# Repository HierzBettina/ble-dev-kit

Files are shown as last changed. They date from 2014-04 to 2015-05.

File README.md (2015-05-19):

*Note*: I have ceased working on projects with the HM-10 and the CC2541. The difficulties of dealing with the IAR toolchain are too great. I now recommend [ARM mbed solutions](https://developer.mbed.org/platforms/Nordic-nRF51822/) if you intend to pursue developing a BLE peripheral. I am leaving the resources I was able to gather online in case someone has use for them, but I cannot provide support.

BLE Dev Kit
====

Getting into low power Bluetooth peripheral prototyping can get expensive quickly. This project aims to chart out and the document the cheapest, easiest way to create a true, custom peripheral with its own profile. Head on over the [wiki](https://github.com/nickswalker/ble-dev-kit/wiki) to read more.

Hardware
----
A sub ten dollar CC2541 development board based on the HM-10 module. This board is a fork of Ladvien's excellent work with the module.
 
Firmware
----
On-board application and profile examples.

Software
----
Client application examples (iOS).

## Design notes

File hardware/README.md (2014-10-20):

### Who are These Boards For?

Two groups of people: Those wanting to get breadboard, quasi-UART-over-BLE through the modules’ firmware and those wanting a cheaper, more flexible alternative to TI's CC2541 dev kits.

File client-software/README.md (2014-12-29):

Client Software
====

RSSI Probe
------

An iOS app that displays the RSSI values of three devices. Load a profile that advertises at a regular interval onto some HM-10s and then code their UUIDs into the source. Experiment with interesting arrangements and configurations. Includes a useful CSV logging capability so you can work with the data. Just plug your device into iTunes when your done and copy the log from the applications pane. Note that the app will not compile in the simulator; CoreBluetooth requires an actual device.

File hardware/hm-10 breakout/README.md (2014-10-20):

HM-10 Breakout Board
====================

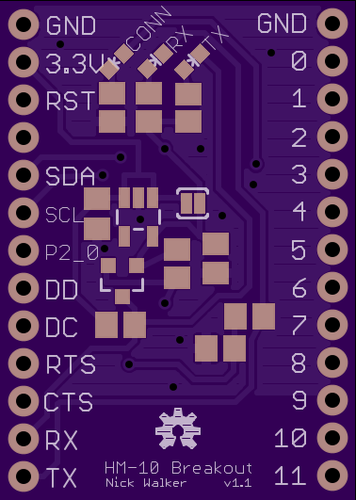
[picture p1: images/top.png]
Top

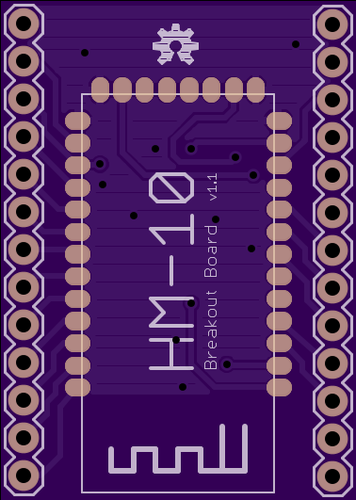
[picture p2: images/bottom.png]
Bottom


This is a slight modification of [Ladvien's board](https://github.com/Ladvien/HM-10). This version has more accurate pin notations and removes routes to unused pins on the HM-10, thereby shrinking the overall footprint of the board. 
The HM-10's on board TI CC2541 is fully programmable with CC-Debugger or SmartRF04EB. See this repo's [wiki](https://github.com/nickswalker/HM-10-breakout-board/wiki) for more resources.

## Bill of Materials

If you are planning on ordering the PCB through OSHPark, keep in mind that you will receive three copies. You may want to go ahead and order three times as many components. Digi-Key numbers are provided as a courtesy; check eBay or any other preferred supplier for better pricing. As long as the component matches the packaging a specifications, it should be fine.

At a bare minimum, the PCB and the HM-10 module are required. If you want to use UART but only have the capability of providing 5v, you will want to populate the level conversion components. However, this is /grossly/ inefficient and defeats the purpose of using a low power connection technology. Bridge the solder jumper to bypass the regulator circuit. You may consider simply regulating off board for development, using a cheap level converter like [this one](http://www.ebay.com/itm/1PC-New-5V-3V-IIC-UART-Level-Converter-Module-Adapter-4-Way-For-Arduino-/251384699933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).

Part (Digi-Key #) | Quantity | Optional (Required For)
:---------------- | :-------:| :----------------------
[Breakout PCB](https://oshpark.com/shared_projects/A6hoH6Fi)  | 1 | No
[HM-10 Module](http://www.fasttech.com/products/0/10004051/1292002-ti-cc2540-bluetooth-40-ble-2540-transparent-serial) | 1 | No
[0805 20kΩ Resistor](http://www.digikey.com/product-detail/en/RMCF0805JT20K0/RMCF0805JT20K0CT-ND/1942580) (RMCF0805JT20K0CT-ND) | 1 | Yes (UART level conversion)
[0805 10kΩ Resistor](http://www.digikey.com/product-detail/en/RMCF0805FT10K0/RMCF0805FT10K0DKR-ND/1943341) (RMCF0805FT10K0CT-ND) | 3 | Yes (UART level conversion)
[0603 LED](http://www.digikey.com/product-detail/en/LTST-C191KRKT/160-1447-1-ND/386836) (160-1447-1-ND) | 1 | Yes (LEDs)
[0603 LED (>3v drop)](http://www.digikey.com/product-detail/en/APT1608QBC%2FD/754-1434-1-ND/2163792) (754-1434-1-ND) | 2 | Yes (LEDs)
[0805 470Ω Resistor](http://www.digikey.com/product-detail/en/RMCF0805JG470R/RMCF0805JG470RCT-ND/4425246) (RMCF0805JG470RCT-ND) | 3 | Yes (LEDs)
[SOT-23 MCP1700 Voltage Regulator](http://www.digikey.com/product-detail/en/MCP1700T-3302E%2FTT/MCP1700T3302ETTCT-ND/652677) (MCP1700T3302ETTCT-ND) | 1 | Yes (voltage regulator)
[0805 1uF Capacitor](http://www.digikey.com/product-detail/en/JMK105BJ105KV-F/587-1231-1-ND/931008) (587-1231-1-ND) | 1 | Yes (Voltage regulator)

The silkscreen doesn't include values, so be sure to have it open in front of you while you assemble.

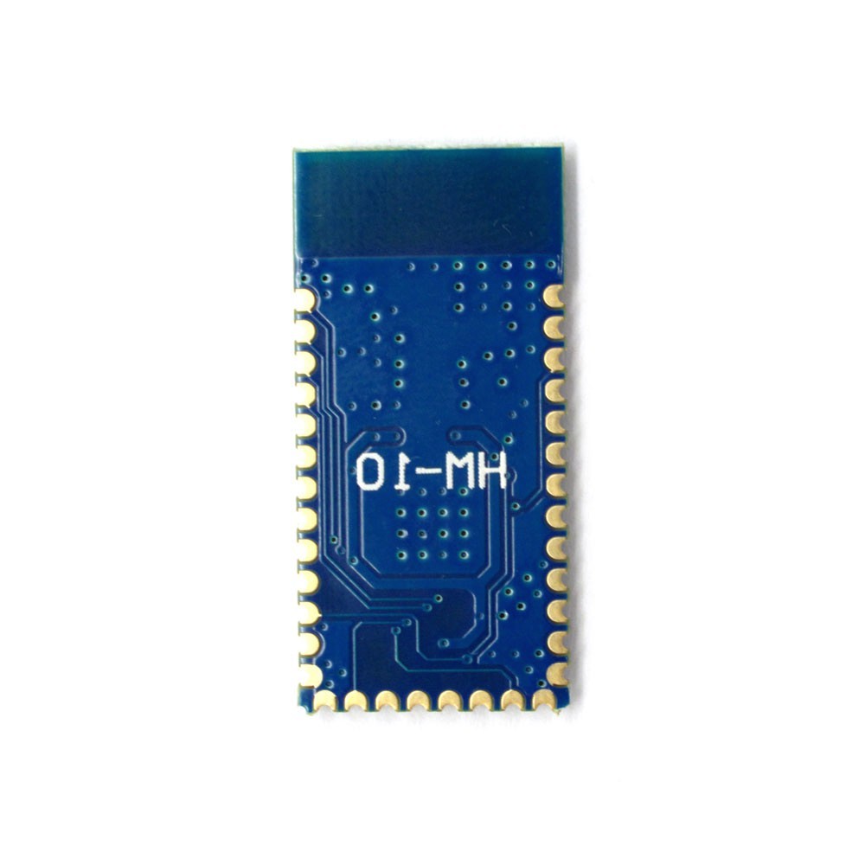
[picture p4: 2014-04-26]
images/hm-10-back.jpg

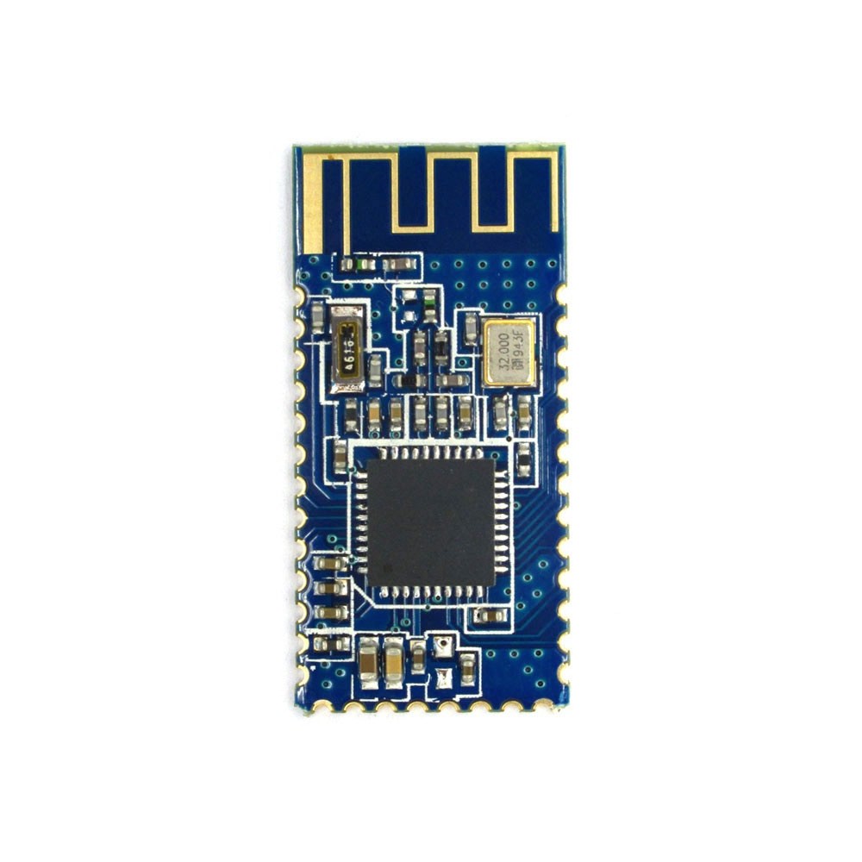
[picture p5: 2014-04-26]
images/hm-10-front.jpg

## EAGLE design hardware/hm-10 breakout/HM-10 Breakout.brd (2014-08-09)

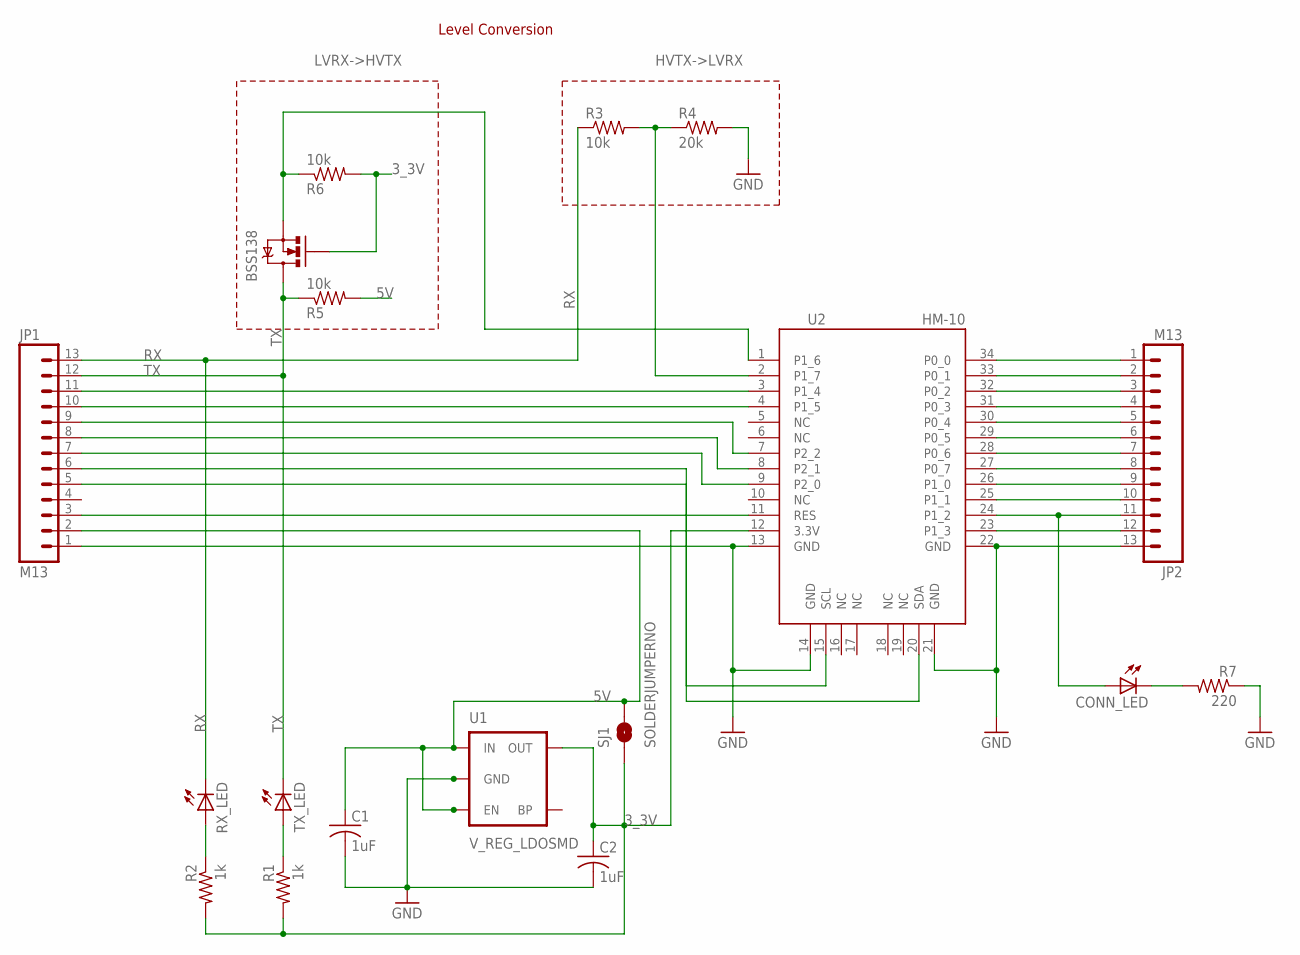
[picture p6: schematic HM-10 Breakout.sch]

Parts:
BSS138: MOSFET-NCHANNELSMD; SOT23-3
C1, C2: 1uF; C0805K
CONN_LED: LED0603; LED-0603
JP1, JP2: M13; 1X13
R1, R2: 1k; M0805
R3, R5, R6: 10k; M0805
R4: 20k; M0805
R7: 220; M0805
RX_LED: LED0603; LED-0603
SJ1: SOLDERJUMPERNO; SJ_2S-NO
TX_LED: LED0603; LED-0603
U1: V_REG_LDOSMD; SOT23-5
U2: HM-10

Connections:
3_3V: BSS138.1 (G), C2.1, R1.2, R2.2, R6.2, SJ1.1, U1.5 (OUT), U2.12 (3.3V)
5V: C1.1, JP1.2, R5.2, SJ1.2, U1.1 (IN), U1.3 (EN)
GND: C1.2, C2.2, JP1.1, JP2.13, R4.2, R7.1, U1.2 (GND), U2.13 (GND), U2.14 (GND), U2.21 (GND), U2.22 (GND)
HVTX->LVRX: R3.2, R4.1, U2.2 (P1_7)
LVRX->HVTX: BSS138.2 (S), R6.1, U2.1 (P1_6)
unnamed: CONN_LED.A, JP2.11, U2.24 (P1_2)
unnamed: JP1.3, U2.11 (RES)
unnamed: JP1.5, U2.15 (SCL)
unnamed: JP1.9, U2.7 (P2_2)
unnamed: JP1.8, U2.8 (P2_1)
unnamed: JP1.7, U2.9 (P2_0)
unnamed: JP2.10, U2.25 (P1_1)
unnamed: JP1.6, U2.20 (SDA)
unnamed: JP1.10, U2.4 (P1_5)
unnamed: JP1.11, U2.3 (P1_4)
unnamed: JP2.9, U2.26 (P1_0)
unnamed: JP2.8, U2.27 (P0_7)
unnamed: JP2.7, U2.28 (P0_6)
unnamed: JP2.6, U2.29 (P0_5)
unnamed: JP2.5, U2.30 (P0_4)
unnamed: JP2.4, U2.31 (P0_3)
unnamed: JP2.3, U2.32 (P0_2)
unnamed: JP2.2, U2.33 (P0_1)
unnamed: JP2.1, U2.34 (P0_0)
unnamed: JP2.12, U2.23 (P1_3)
unnamed: R1.1, TX_LED.A
unnamed: CONN_LED.C, R7.2
unnamed: R2.1, RX_LED.A
RX: JP1.13, R3.1, RX_LED.C
TX: BSS138.3 (D), JP1.12, R5.1, TX_LED.C

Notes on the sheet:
Level Conversion

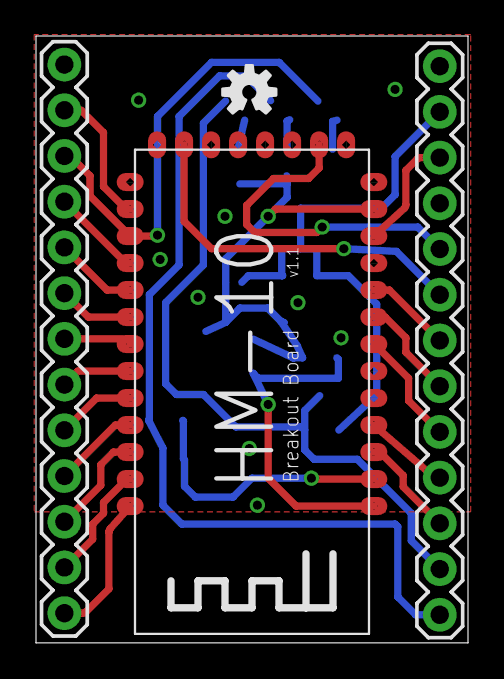
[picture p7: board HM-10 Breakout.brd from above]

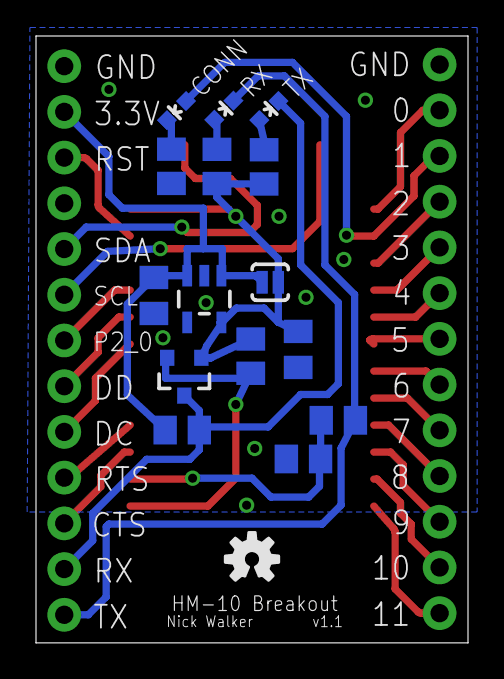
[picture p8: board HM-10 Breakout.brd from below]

Board: 2 copper layers, 24.0 x 33.7 mm, 20 parts (16 on the bottom side), 30 nets.

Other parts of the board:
U$1, U$2: OSHW-LOGO-S

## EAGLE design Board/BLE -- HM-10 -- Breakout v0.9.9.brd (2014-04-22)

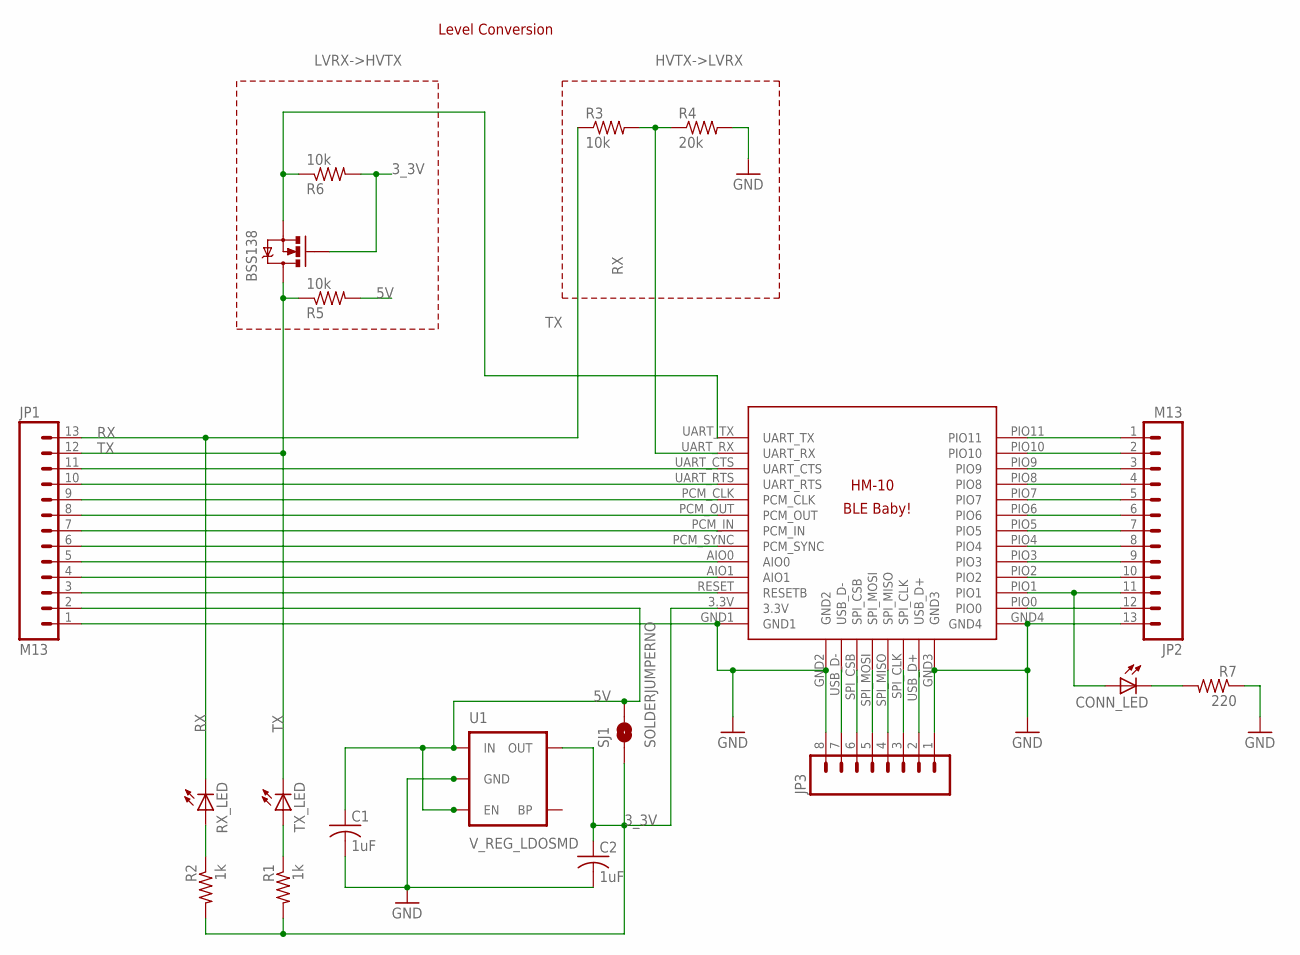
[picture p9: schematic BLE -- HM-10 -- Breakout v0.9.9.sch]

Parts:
BSS138: MOSFET-NCHANNELSMD; SOT23-3
C1, C2: 1uF; C0805K
CONN_LED: LED0603; LED-0603
JP1, JP2: M13; 1X13
JP3: M081X08; 1X08
R1, R2: 1k; M0805
R3, R5, R6: 10k; M0805
R4: 20k; M0805
R7: 220; M0805
RX_LED: LED0603; LED-0603
SJ1: SOLDERJUMPERNO; SJ_2S-NO
TX_LED: LED0603; LED-0603
U1: V_REG_LDOSMD; SOT23-5
U$1: BLE-HM-10

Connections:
3_3V: BSS138.1 (G), C2.1, R1.2, R2.2, R6.2, SJ1.1, U1.5 (OUT), U$1.3.3V
5V: C1.1, JP1.2, R5.2, SJ1.2, U1.1 (IN), U1.3 (EN)
GND: C1.2, C2.2, JP1.1, JP2.13, JP3.1, JP3.8, R4.2, R7.1, U1.2 (GND), U$1.GND1, U$1.GND2, U$1.GND3, U$1.GND4
HVTX->LVRX: R3.2, R4.1, U$1.UART_RX
LVRX->HVTX: BSS138.2 (S), R6.1, U$1.UART_TX
unnamed: CONN_LED.A, JP2.11, U$1.PIO1
unnamed: JP1.3, U$1.RESET (RESETB)
unnamed: JP1.4, U$1.AIO1
unnamed: JP1.5, U$1.AIO0
unnamed: JP1.6, U$1.PCM_SYNC
unnamed: JP1.7, U$1.PCM_IN
unnamed: JP1.8, U$1.PCM_OUT
unnamed: JP1.9, U$1.PCM_CLK
unnamed: JP1.10, U$1.UART_RTS
unnamed: JP1.11, U$1.UART_CTS
unnamed: JP2.1, U$1.PIO11
unnamed: JP2.2, U$1.PIO10
unnamed: JP2.3, U$1.PIO9
unnamed: JP2.4, U$1.PIO8
unnamed: JP2.5, U$1.PIO7
unnamed: JP2.6, U$1.PIO6
unnamed: JP2.7, U$1.PIO5
unnamed: JP2.8, U$1.PIO4
unnamed: JP2.9, U$1.PIO3
unnamed: JP2.10, U$1.PIO2
unnamed: R1.1, TX_LED.A
unnamed: JP2.12, U$1.PIO0
unnamed: CONN_LED.C, R7.2
unnamed: R2.1, RX_LED.A
unnamed: JP3.2, U$1.USB_D+
unnamed: JP3.3, U$1.SPI_CLK
unnamed: JP3.4, U$1.SPI_MISO
unnamed: JP3.5, U$1.SPI_MOSI
unnamed: JP3.6, U$1.SPI_CSB
unnamed: JP3.7, U$1.USB_D-
RX: JP1.13, R3.1, RX_LED.C
TX: BSS138.3 (D), JP1.12, R5.1, TX_LED.C

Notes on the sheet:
Level Conversion

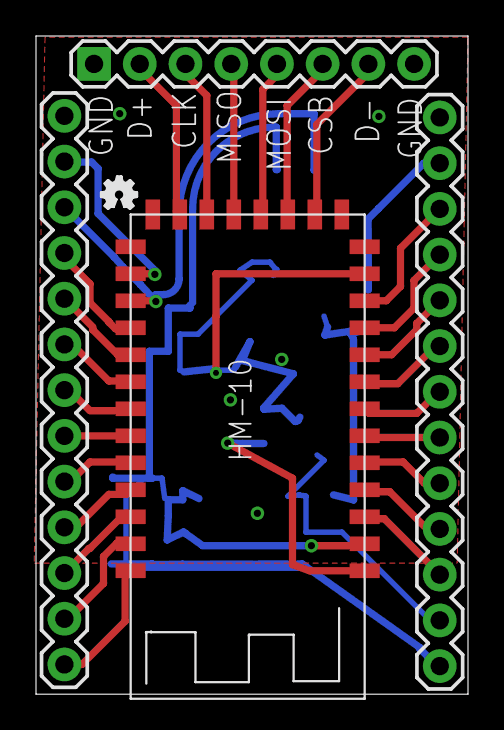
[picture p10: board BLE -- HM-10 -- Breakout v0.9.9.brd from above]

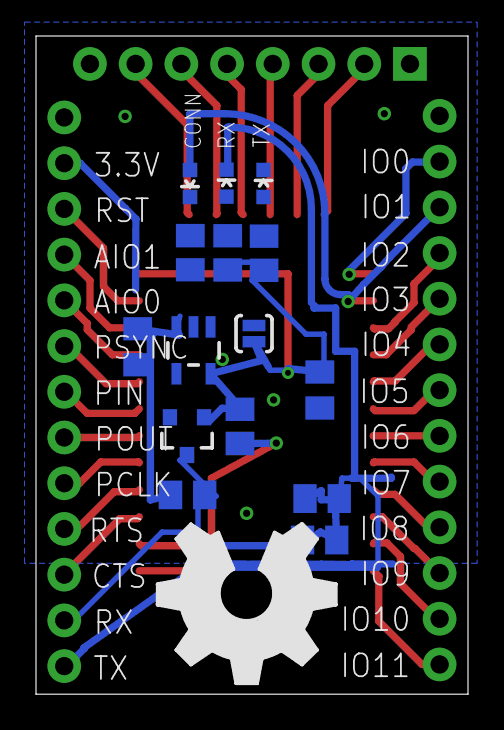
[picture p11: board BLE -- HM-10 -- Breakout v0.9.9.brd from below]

Board: 2 copper layers, 24.0 x 36.6 mm, 21 parts (16 on the bottom side), 37 nets.

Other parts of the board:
U$2: OSHW_FILLX350_NOTEXT
U$3: OSHW_FILLX70_NOTEXT

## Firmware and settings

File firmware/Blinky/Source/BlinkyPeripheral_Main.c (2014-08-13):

/* Hal Drivers */
#include "hal_types.h"
#include "hal_key.h"
#include "hal_timer.h"
#include "hal_drivers.h"
#include "hal_led.h"

/* OSAL */
#include "OSAL.h"
#include "OSAL_Tasks.h"
#include "OSAL_PwrMgr.h"
#include "osal_snv.h"

/**************************************************************************************************
 * FUNCTIONS
 **************************************************************************************************/

/* This callback is triggered when a key is pressed */
void MSA_Main_KeyCallback(uint8 keys, uint8 state);

int main(void)
{
  /* Initialize hardware */
  HAL_BOARD_INIT();

  /* Initialze the HAL driver */
  HalDriverInit();

  /* Initialize NV system */
  osal_snv_init();

  /* Initialize the operating system */
  osal_init_system();

  /* Enable interrupts */
  HAL_ENABLE_INTERRUPTS();

  #if defined ( POWER_SAVING )
    osal_pwrmgr_device( PWRMGR_BATTERY );
  #endif

  /* Start OSAL */
  osal_start_system(); // No Return from here

  return 0;
}

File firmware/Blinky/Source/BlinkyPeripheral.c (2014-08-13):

#include "bcomdef.h"
#include "OSAL.h"
#include "OSAL_PwrMgr.h"

#include "OnBoard.h"
#include "hal_adc.h"
#include "hal_led.h"
#include "hal_key.h"
#include "hal_lcd.h"

#include "gatt.h"

#include "hci.h"

#include "gapgattserver.h"
#include "gattservapp.h"
#include "devinfoservice.h"
#include "blinkyProfile.h"

#include "peripheral.h"

#include "gapbondmgr.h"

#include "BlinkyPeripheral.h"

#if defined FEATURE_OAD
  #include "oad.h"
  #include "oad_target.h"
#endif


/*********************************************************************
 * CONSTANTS
 */

// How often to perform periodic event
#define SBP_PERIODIC_EVT_PERIOD                   500

// What is the advertising interval when device is discoverable (units of 625us, 160=100ms)
#define DEFAULT_ADVERTISING_INTERVAL          160

// Limited discoverable mode advertises for 30.72s, and then stops
// General discoverable mode advertises indefinitely

#define DEFAULT_DISCOVERABLE_MODE             GAP_ADTYPE_FLAGS_GENERAL


// Minimum connection interval (units of 1.25ms, 80=100ms) if automatic parameter update request is enabled
#define DEFAULT_DESIRED_MIN_CONN_INTERVAL     80

// Maximum connection interval (units of 1.25ms, 800=1000ms) if automatic parameter update request is enabled
#define DEFAULT_DESIRED_MAX_CONN_INTERVAL     800

// Slave latency to use if automatic parameter update request is enabled
#define DEFAULT_DESIRED_SLAVE_LATENCY         0

// Supervision timeout value (units of 10ms, 1000=10s) if automatic parameter update request is enabled
#define DEFAULT_DESIRED_CONN_TIMEOUT          1000

// Whether to enable automatic parameter update request when a connection is formed
#define DEFAULT_ENABLE_UPDATE_REQUEST         TRUE

// Connection Pause Peripheral time value (in seconds)
#define DEFAULT_CONN_PAUSE_PERIPHERAL         6

// Company Identifier: Texas Instruments Inc. (13)
#define TI_COMPANY_ID                         0x000D

#define INVALID_CONNHANDLE                    0xFFFF

// Length of bd addr as a string
#define B_ADDR_STR_LEN                        15

/*********************************************************************
 * LOCAL VARIABLES
 */
static uint8 simpleBLEPeripheral_TaskID;   // Task ID for internal task/event processing

static gaprole_States_t gapProfileState = GAPROLE_INIT;

// GAP - SCAN RSP data (max size = 31 bytes)
static uint8 scanRspData[] =
{
  // complete name
  0x06,   // length of this data
  GAP_ADTYPE_LOCAL_NAME_COMPLETE,
  0x42,   // 'B'
  0x6c,   // 'l'
  0x69,   // 'i'
  0x6e,   // 'n'
  0x6b,   // 'k'
  0x79,   // 'y'
  
  // connection interval range
  0x05,   // length of this data
  GAP_ADTYPE_SLAVE_CONN_INTERVAL_RANGE,
  LO_UINT16( DEFAULT_DESIRED_MIN_CONN_INTERVAL ),   // 100ms
  HI_UINT16( DEFAULT_DESIRED_MIN_CONN_INTERVAL ),
  LO_UINT16( DEFAULT_DESIRED_MAX_CONN_INTERVAL ),   // 1s
  HI_UINT16( DEFAULT_DESIRED_MAX_CONN_INTERVAL ),

  // Tx power level
  0x02,   // length of this data
  GAP_ADTYPE_POWER_LEVEL,
  0       // 0dBm
};

// GAP - Advertisement data (max size = 31 bytes, though this is
// best kept short to conserve power while advertisting)
static uint8 advertData[] =
{
  // Flags; this sets the device to use limited discoverable
  // mode (advertises for 30 seconds at a time) instead of general
  // discoverable mode (advertises indefinitely)
  0x02,   // length of this data
  GAP_ADTYPE_FLAGS,
  DEFAULT_DISCOVERABLE_MODE | GAP_ADTYPE_FLAGS_BREDR_NOT_SUPPORTED,

  // service UUID, to notify central devices what services are included
  // in this peripheral
  0x03,   // length of this data
  GAP_ADTYPE_16BIT_MORE,      // some of the UUID's, but not all
  LO_UINT16( BLINKYPROFILE_SERV_UUID ),
  HI_UINT16( BLINKYPROFILE_SERV_UUID ),

};

// GAP GATT Attributes
static uint8 attDeviceName[GAP_DEVICE_NAME_LEN] = "Simple BLE Peripheral";

/*********************************************************************
 * LOCAL FUNCTIONS
 */
static void simpleBLEPeripheral_ProcessOSALMsg( osal_event_hdr_t *pMsg );
static void peripheralStateNotificationCB( gaprole_States_t newState );
static void performPeriodicTask( void );
static void blinkyProfileChangeCB( uint8 paramID );


/*********************************************************************
 * PROFILE CALLBACKS
 */

// GAP Role Callbacks
static gapRolesCBs_t simpleBLEPeripheral_PeripheralCBs =
{
  peripheralStateNotificationCB,  // Profile State Change Callbacks
  NULL                            // When a valid RSSI is read from controller (not used by application)
};

// GAP Bond Manager Callbacks
static gapBondCBs_t simpleBLEPeripheral_BondMgrCBs =
{
  NULL,                     // Passcode callback (not used by application)
  NULL                      // Pairing / Bonding state Callback (not used by application)
};

// Simple GATT Profile Callbacks
static blinkyProfileCBs_t simpleBLEPeripheral_BlinkyProfileCBs =
{
  blinkyProfileChangeCB    // Charactersitic value change callback
};
/*********************************************************************
 * PUBLIC FUNCTIONS
 */
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

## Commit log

2014-04-22 Update readme
    Update BoM
    Add images of board
    New links
2014-04-22 Remove variants
    Start updating board
    Normalize PCB typography
    [BLE -- HM-10 -- Breakout v0.9.9.brd, BLE -- HM-10 -- Breakout v0.9.9.sch]
2014-04-26 Overhaul PCB
    Cleanup typography on silkscreen
    Remove no connection lines
    Replace HM-10 Eagle part with a more faithful version
    [HM-10 Breakout.brd, HM-10 Breakout.sch]
2014-04-26 Update documentation
    Include photos of hm-10 front and back
    Updated readme to reflect changes to the board
2014-04-29 Update README.md
    Add part number for capacitor
2014-05-01 Update README.md
    Clean up link formatting
    Switch part references to CC2451 as per recent change in HM10 modules
2014-05-04 Shrink board
    Remove top row of pins
    Change silkscreen to note change to SPI over USB
    Add version number and text to silkscreen
    [HM-10 Breakout.brd, HM-10 Breakout.sch]
2014-05-18 Shift components toward center on bottom layer
    Make pin description text larger
    Switch from DBGD to DD notation
    Rotate LED labels 45 degrees
    [HM-10 Breakout.brd]
2014-05-25 Tented vias
    Cleaned up routes more
    [HM-10 Breakout.brd]
2014-05-25 Update images
    Rotate LEDs 45 degrees
    [HM-10 Breakout.brd]
2014-06-01 Add OSHW logos back
    Add attribution text to bottom layer
    [HM-10 Breakout.brd]
2014-06-01 Update images
    [HM-10 Breakout.brd]
2014-06-01 Update README.md
    Add note about the solder jumper
2014-06-01 Update README.md
    Add note about why the regulator is not preferable.
2014-08-09 Fix swapped debug signals
    Update images
    Update eagle files to v7
    [HM-10 Breakout.brd]
2014-08-13 Pivot the project
    Start moving the project toward a more inclusive goal
    Add a blinky firmware example
    [buildConfig.cfg]
2014-08-13 Move hm-10 breakout to own directory
    Room to accommodate future boards (HM-11)
    [HM-10 Breakout.brd, HM-10 Breakout.sch]
2014-08-13 Make Blinky iOS controllable
    Remove build directories from git
    Fix an issue with the attribute macros related to UUID length
    Add HM-10 pin defines
    Add proper custom dev info service
    [buildConfig.cfg]
2014-10-20 Add RSSI Probe client example
    Tweak readmes
2014-10-20 Improve logging
    Add a log event counter to make taking samples easier
    Split scanning feature to use its own log
    Improve CSV formating

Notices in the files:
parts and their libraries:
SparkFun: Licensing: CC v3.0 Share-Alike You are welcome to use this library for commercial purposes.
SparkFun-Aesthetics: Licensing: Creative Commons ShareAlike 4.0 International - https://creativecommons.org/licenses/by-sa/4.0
